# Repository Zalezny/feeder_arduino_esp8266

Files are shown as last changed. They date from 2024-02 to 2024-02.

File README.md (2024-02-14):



# Automated Feeder

An Automated Feeder designed for guinea pigs (and adaptable for other animals). It operates using an ESP8266 microcontroller. As part of the project, a rotating screw mechanism was 3D printed to dispense the feed.

## Scheme (Eagle)

black

## Board (Eagle)

board

## Parts

- Processor: ESP8266 WiFi
- LCD 4x20 green LCD-01136
- Clock RTC: MSX RTC DS1307
- Stepper motor: 28BYJ-48
- Power: Impulse Power Supply 3-12V/1.2A (for this project 5V)
- Mechanism: Rotating Screw (Printer 3D)

## How it works 

When you connect the feeder to power, the program will start counting down, and when it reaches zero, the feeder will begin dispensing feed.

ESP8266 is configured to REST Server with endpoints like /setTimer - set hour, minute, second or /setState - set pause, resume or restart

Pierwszy obraz
Drugi obraz
Drugi obraz

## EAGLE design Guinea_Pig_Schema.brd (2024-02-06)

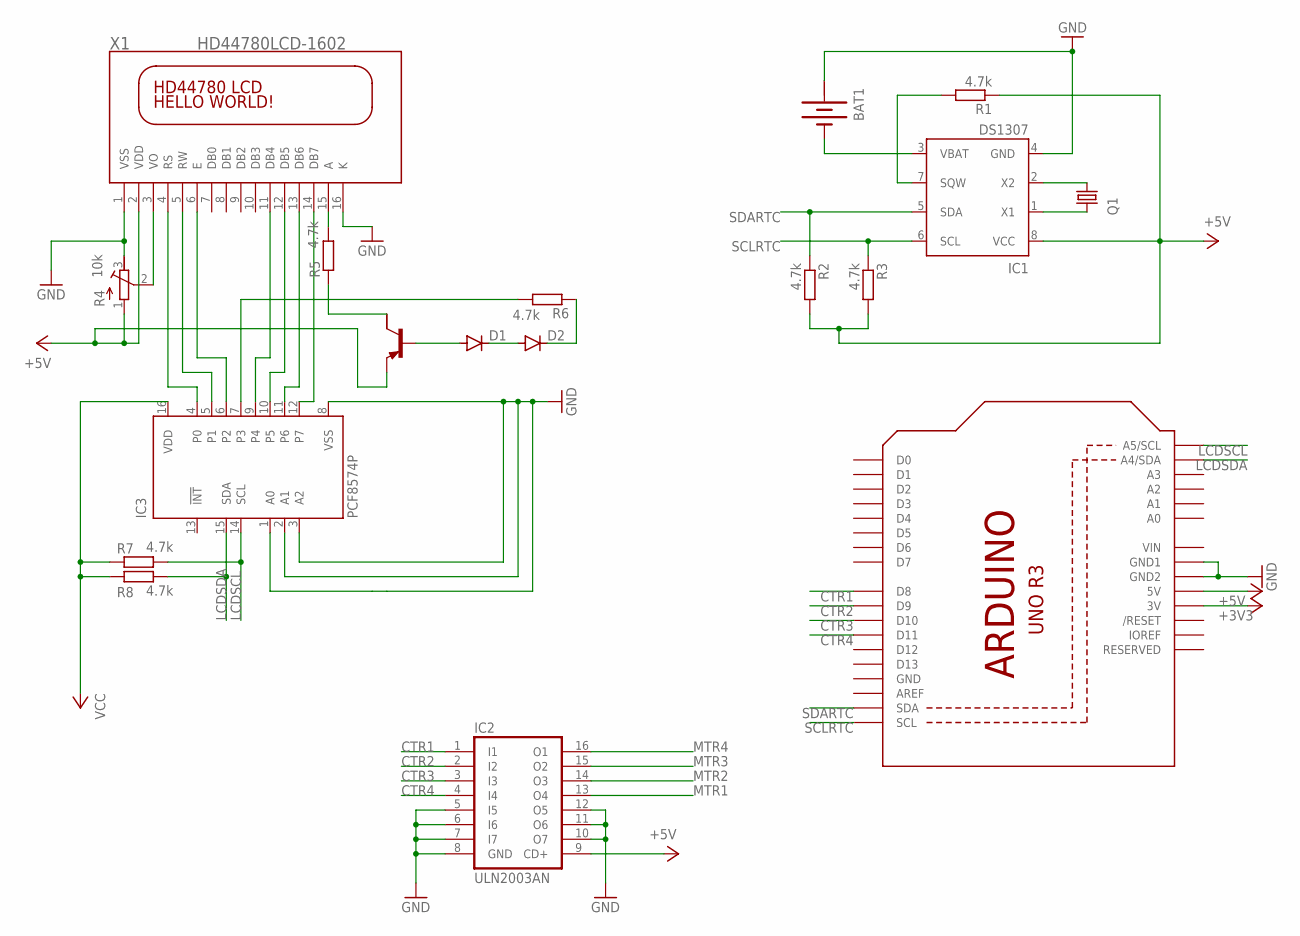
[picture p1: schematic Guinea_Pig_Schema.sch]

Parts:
BAT1: BATTERY
D1, D2: DIODE-DO-214AC; DO-214AC
IC1: DS1307; DIL08
IC2: ULN2003AN; DIL16
IC3: PCF8574P; DIL16
Q1: CRYSTAL68SMX; 86SMX
Q2: PNP-TRANSISTIOR-2COLSOT89; SOT89
R1, R2, R3, R5, R6, R7, R8: 4.7k; R1206
R4: 10k; RTRIM3224X
U1: ARDUINOR3-BPLACE
X1: HD44780LCD-1602; LCD1602

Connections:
+: BAT1.+@1 (+)
+3V3: U1.3V
+5V: IC2.9 (CD+), U1.5V
CTR1: IC2.1 (I1), U1.D8
CTR2: IC2.2 (I2), U1.D9
CTR3: IC2.3 (I3), U1.D10
CTR4: IC2.4 (I4), U1.D11
GND: BAT1.+, IC1.4 (GND), IC2.5 (I5), IC2.6 (I6), IC2.7 (I7), IC2.8 (GND), IC2.10 (O7), IC2.11 (O6), IC2.12 (O5), IC3.1 (A0), IC3.2 (A1), IC3.3 (A2), IC3.8 (VSS), R4.3 (E), U1.GND, U1.GND1, U1.GND2, X1.1 (VSS), X1.16 (K)
LCDSCL: IC3.14 (SCL), R7.2, U1.A5 (A5/SCL)
LCDSDA: IC3.15 (SDA), R8.2, U1.A4 (A4/SDA)
MTR1: IC2.13 (O4)
MTR2: IC2.14 (O3)
MTR3: IC2.15 (O2)
MTR4: IC2.16 (O1)
unnamed: IC1.2 (X2), Q1.1
unnamed: IC1.1 (X1), Q1.4 (2)
unnamed: BAT1.-, IC1.3 (VBAT)
unnamed: R4.2 (S), X1.3 (VO)
unnamed: IC1.7 (SQW), R1.2
unnamed: IC3.4 (P0), X1.4 (RS)
unnamed: IC3.5 (P1), X1.5 (RW)
unnamed: IC3.6 (P2), X1.6 (E)
unnamed: IC3.9 (P4), X1.11 (DB4)
unnamed: IC3.10 (P5), X1.12 (DB5)
unnamed: IC3.11 (P6), X1.13 (DB6)
unnamed: IC3.12 (P7), X1.14 (DB7)
unnamed: R5.2, X1.15 (A)
unnamed: Q2.2 (C), R5.1
unnamed: IC3.7 (P3), R6.2
unnamed: D1.A, Q2.1 (B)
unnamed: D1.C, D2.A
unnamed: D2.C, R6.1
SCLRTC: IC1.6 (SCL), R3.1, U1.SCL
SDARTC: IC1.5 (SDA), R2.1, U1.SDA
VCC: IC1.8 (VCC), IC3.16 (VDD), R1.1, R2.2, R3.2, R7.1, R8.1
VDD: Q2.3 (E), R4.1 (A), X1.2 (VDD)
VIN: U1.VIN

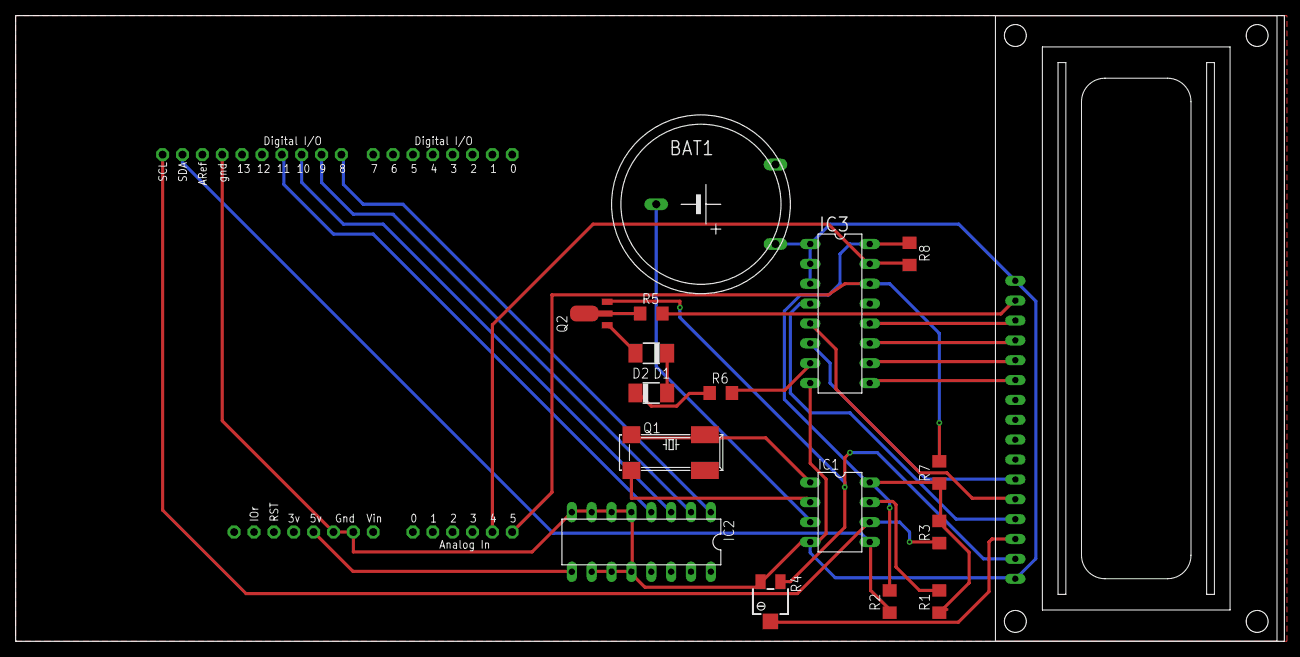
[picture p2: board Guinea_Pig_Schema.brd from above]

Board: 2 copper layers, 162.2 x 80.0 mm, 18 parts (0 on the bottom side), 30 nets.

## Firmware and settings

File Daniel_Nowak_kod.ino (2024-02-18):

#include "LiquidCrystal_I2C.h"
#include "wifi_env.h"
#include <Wire.h>
#include <Stepper.h>
#include <TimeLib.h>
#include <RTClib.h>
#include <ESP8266WiFi.h>
#include <ESP8266WebServer.h>
#include <ESP8266mDNS.h>
#include <WiFiClient.h>
#include <ArduinoJson.h>

unsigned long previous = 0;

RTC_DS1307 DS1307_RTC;

#define IN1 14
#define IN2 12
#define IN3 13
#define IN4 15

LiquidCrystal_I2C lcd(0x27, 20, 4);
Stepper mojSilnik(32, IN1, IN3, IN2, IN4);
tmElements_t tm;

int h = 1;
long m = 0;
long s = 10;
long int countdown_time;
long int break_time;
bool pause = false;

#define HTTP_REST_PORT 8080
ESP8266WebServer server(HTTP_REST_PORT);

void initTimer() {
  long currentTime = (tm.Hour * 3600L + tm.Minute * 60 + tm.Second);
  long expectedTime = ((h * 3600L) + m * 60 + s);
  countdown_time = expectedTime - currentTime;
}
void initFeeder() {
  initTimer();
  lcd.begin();
  lcd.clear();
  lcd.backlight();
}

void initWiFi() {
  WiFi.mode(WIFI_STA);
  WiFi.begin(OWN_SSID, OWN_PASSWORD);
  Serial.println("");

  while (WiFi.status() != WL_CONNECTED) {
    delay(500);
    Serial.print(".");
  }
  Serial.println("");
  Serial.print("Connected to ");
  Serial.println(OWN_SSID);
  Serial.print("IP address: ");
  Serial.println(WiFi.localIP());

  if (MDNS.begin("feeder")) {
    Serial.println("MDNS responder started");
  }
}
void getHelloWord() {
  server.send(200, "text/json", "{\"name\": \"Hello world\"}");
}

void restServer() {
  server.on("/", HTTP_GET, []() {
    server.send(200, F("text/html"), F("Welcome to the Feeder REST"));
  });
  server.on(F("/helloWorld"), HTTP_GET, getHelloWord);
  server.on(F("/setTimer"), HTTP_POST, setTimer);
  server.on(F("/setState"), HTTP_POST, setState);
}

void handleNotFound() {
  String message = "File Not Found\n\n";
  message += "URI: ";
  message += server.uri();
  message += "\nMethod: ";
  message += (server.method() == HTTP_GET) ? "GET" : "POST";
  message += "\nArguments: ";
  message += server.args();
  message += "\n";
  for (uint8_t i = 0; i < server.args(); i++) {
    message += " " + server.argName(i) + ": " + server.arg(i) + "\n";
  }
  server.send(404, "text/plain", message);
}

void handleIssue() {
  DynamicJsonDocument doc(512);
  doc["status"] = "KO";
  doc["message"] = F("No data found, or incorrect!");

  Serial.print(F("Stream..."));
  String buf;
  serializeJson(doc, buf);

  server.send(400, F("application/json"), buf);
  Serial.print(F("done."));
}

void handleBodyError(DeserializationError error) {
  Serial.print(F("Error parsing JSON "));
  Serial.println(error.c_str());

  String msg = error.c_str();

  server.send(400, F("text/html"),
              "Error in parsing json body! <br>" + msg);
}

void setState() {
  String postBody = server.arg("plain");
  Serial.println(postBody);

  DynamicJsonDocument doc(512);
  DeserializationError error = deserializeJson(doc, postBody);
  if (error) {
    handleBodyError(error);
  } else {
    JsonObject postObj = doc.as<JsonObject>();

    Serial.print(F("HTTP Method: "));
    Serial.println(server.method());

    if (server.method() == HTTP_POST) {
      if (postObj.containsKey("pause")) {

        Serial.println(F("done."));

        pause = (bool)postObj["pause"];
        Serial.println(pause);


        DynamicJsonDocument doc(512);
        doc["status"] = "OK";

        Serial.print(F("Stream..."));
        String buf;
        serializeJson(doc, buf);

        server.send(201, F("application/json"), buf);
        Serial.print(F("done."));

      } else {
        handleIssue();
      }
    }
  }
}

void setTimer() {
  String postBody = server.arg("plain");
  Serial.println(postBody);

  DynamicJsonDocument doc(512);
  DeserializationError error = deserializeJson(doc, postBody);
  if (error) {
    handleBodyError(error);
  } else {
    JsonObject postObj = doc.as<JsonObject>();

    Serial.print(F("HTTP Method: "));
    Serial.println(server.method());

    if (server.method() == HTTP_POST) {
      if (postObj.containsKey("hour") && postObj.containsKey("minutes") && postObj.containsKey("seconds")) {

        Serial.println(F("done."));

        // Here store data or doing operation
        h = (int)postObj["hour"];
        m = (long)postObj["minutes"];
        s = (long)postObj["seconds"];
        initTimer();
        // Create the response
        // To get the status of the result you can get the http status so
        // this part can be unusefully
        DynamicJsonDocument doc(512);
        doc["status"] = "OK";

        Serial.print(F("Stream..."));
        String buf;
        serializeJson(doc, buf);

        server.send(201, F("application/json"), buf);
        Serial.print(F("done."));

      } else {
        handleIssue();
      }
    }
  }
}
void setup() {
  Serial.begin(9600);
  Wire.begin();
  if (!DS1307_RTC.begin()) {
    Serial.println("Couldn't find RTC");
    // while(1);
  }
  DS1307_RTC.adjust(DateTime(F(__DATE__), F(__TIME__)));

  initFeeder();
  initWiFi();
  restServer();
  server.onNotFound(handleNotFound);
  server.begin();
  Serial.println("HTTP server started");
#ifndef ESP8266
  while (!Serial)
    ;  // wait for serial port to connect. Needed for native USB
#endif
}

void loop() {
  server.handleClient();
  long countdowntime_seconds;

  if (pause) {
    countdowntime_seconds = countdown_time - previous;
  } else {
    countdowntime_seconds = countdown_time - (millis() / 1000);
      Serial.println(millis() / 1000);

  }
  if (countdowntime_seconds >= 0) {
    long countdown_hour = countdowntime_seconds / 3600;
    long countdown_minute = ((countdowntime_seconds / 60) % 60);
    long countdown_sec = countdowntime_seconds % 60;
    lcd.setCursor(0, 0);
    if (pause) {
      lcd.print("Pause na czasie: ");

    } else {
      lcd.print("Czas do wydania: ");
    }
    lcd.setCursor(0, 1);
    if (countdown_hour < 10) {
      lcd.print("0");
    }
    lcd.print(countdown_hour);
    lcd.print(":");
    if (countdown_minute < 10) {
      lcd.print("0");
    }
    lcd.print(countdown_minute);
    lcd.print(":");
    if (countdown_sec < 10) {
      lcd.print("0");
    }
    lcd.print(countdown_sec);
    if (countdowntime_seconds == 0) {
      lcd.setCursor(0, 1);
      lcd.print("");
      lcd.print("Wydawanie...");
      mojSilnik.setSpeed(1000);
      mojSilnik.step(-10240);
      lcd.clear();
      previous = (millis() / 1000);
      initTimer();
      digitalWrite(IN1, LOW);
      digitalWrite(IN2, LOW);
      digitalWrite(IN3, LOW);
      digitalWrite(IN4, LOW);
    }
  }
}

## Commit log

2024-02-06 feeder schema and board
    [Guinea_Pig_Schema.brd, Guinea_Pig_Schema.sch]
2024-02-07 clean code for Feeder and Timer
2024-02-08 fix rtc and add init settings ip
    [Daniel_Nowak_kod.ino]
2024-02-09 Create post method for time and handle errors
    [Daniel_Nowak_kod.ino]
2024-02-11 fix of parse to int and long. Fix clock
    [Daniel_Nowak_kod.ino]
